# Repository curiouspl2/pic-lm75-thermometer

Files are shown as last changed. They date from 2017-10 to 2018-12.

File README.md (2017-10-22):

# pic-lm75-thermometer
pic12f629 i2c based lm75 thermometer with many ifdef options

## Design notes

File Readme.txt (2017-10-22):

.asm and .hex file for pic include gnuplot nessesities.
you can modify baudrate in the source, i've choosed 300bps
personally because it is easy to implement it for i.e. audio modem,
or optic link - faster baud rates would be problematic, and we need
such solutions because we want galvanic isolation to protect 
(expensive) PC from i.e. lightning strike induced currents.

shell script inserts date to stream from serial port. 
pic could theoretically insert own date, but it would 
1)drift 
2)make it impossible to enter sleep mode
3)increase power consumption
4)take more time to transmit over serial line

the resulting stream can be redirected to file , which can be later 
used by gnuplot to draw nie plot of temperature.

another , simpler approach would be to make pic emit also index number, 
which could be then used by gnuplot directly as X axis.
current approach is just appropriate for 'pc thermometer'.

scripts for RRD are added for convience - they are tested, and fully operational.

!!! power considerations !!!

with use of low-power lp2950 voltage regulator, and 4700uF and 2200uF capacitors 
and ad3232 (max232 equiv),
it was possible to transmit data out of 8 sensors powered from single serial port.

additional accuracy code (0.125C) for lm75A and adt75A was added, and it seems
that such amount of data is on very edge of power capacity of serial port.

addition of more capacitors is imho recommended to maintain stable supply, 
and if outdoor use is planned - perhaps small solar cell would also help.
(electronics require just 3.3V)

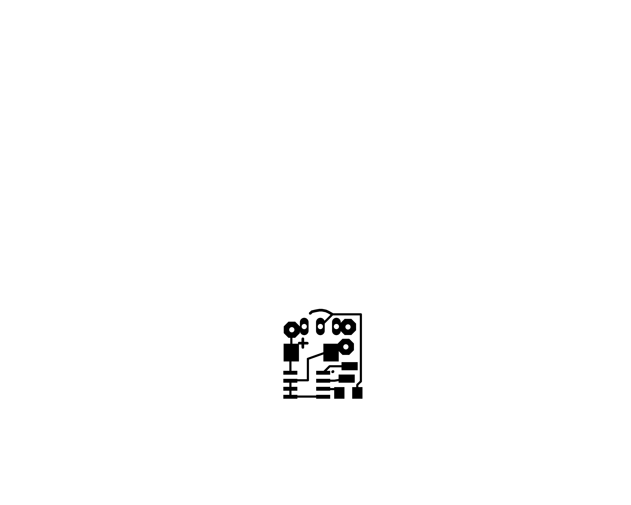
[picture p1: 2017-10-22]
lm75_daughterboard_00.png

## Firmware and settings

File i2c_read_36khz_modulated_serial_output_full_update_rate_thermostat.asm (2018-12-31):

;*******************************************************************
;
;	simple i2c thermometer
;
;	i2c thermometers in, 36khz modulated (IR compat) serial out, 
;	shift register based display with CLOCK and DATA. 
;	to interface to computer use TSOP infrared demodulator with it's output tied to RX pin (ttl)
;	TSOP works optimally at 1200bps. 
; 	if you want to switch to normal bit-banged serial - you must hack the serial routines yourself
;	(i still did not got to it, but i've left plenty of commented-out code to make it simple)
;	
;	there are few fixmes, lot of spaghetti and bit of confusing assumptions, 
; 	 but code is tested and does it's job fine.
;
;	
;*******************************************************************

;-----------features 

#define infrared_serial_output
	;//fixme - not really ifdef'd propelry yet
	; 36khz modulated serial output 
#ifdef 	infrared_serial_output
;#define splash_message
	; greeting/splash message on init/reset
;#define calibration_phase 
	;uncomment to display OSCCAL values (and calibrate serial out)
#endif 	infrared_serial_output

;#define shutdown_mode 
	; shut down lm75 after operations
;#define  sleep_mode 
	; sleep for delay
;#define  shift_register_display
	; required to have any shift register routines at all 
;#define	cooling_mode
	;//fixme 
	; global cooling or heating mode of thermostat. should be selectable for each sensor independently,
	; and from EEPROM... 
	; requires re-make of shutdown routines which mess with config register as a whole. 
	; right now setting affects ALL sensors. not defining means sensor will try to heat to set temp (active high)
#define	pseudo_analog_keyboard
	; pseudo analog keyboard. it sets KEY_[n] low, measures time taking it to get high again,
	; then sets it high and measures time taking it to get low. 
	; this is stored in two variables allowing to implement few types of keyboards. 

#ifdef	pseudo_analog_keyboard
#define	simple_two_key_keyboard
	; this is simplest two keys implementation. 
	; it requires 100nF cap and two buttons with 100ohm resistors (one to Vss , one to Vdd)
	; pros - not dependent on temperature, quality of capacitor etc. 
;#define analog_ladder_keyboard
	; using 100nF cap and set of resistors to change discharge and charge times in series with each switch. 
	;//fixme - currently not implemented
#ifdef	infrared_serial_output
#define	pseudo_analog_keyboard_infrared_serial_debug 
	;debug detected 0to1 and 1to0 transition times of keyboard
	;usefull to tune up resistor ladder keyboard resistors
#endif  infrared_serial_output

#endif 	pseudo_analog_keyboard

;------formatting
;//fixme 
; it would be nice to create new formatting theme for tv terminals displays
; idea would be to clear screen and then nicely format all sensors output so they appear in columns
; along with their additional settings like thermostats and some text descriptions 
; like :
;no  actual/setpoint/hyst
;1	22 / 24 / 22 - living room - heat pump
;2	10 / 99 / 99 - outside
;3	10 / 4 	/ 3  - garage heated with ground heat pump
;4 	-4 / -5 / -4 - fridge
;5 	 8 / 10 / 8  - fridge out to garage heat buffer
;6 	40 / 98 / 85 - solar collector critical - dump heat to garage buffer
;7	40 / 35 / 30 - solar collector low power pump
;8	25 / 25 / 30 - hybrid solar cell cooling

;#define  shift_register_display_0to7
	; use shift register display , order 0 to 7
;#define  shift_register_display_7to0
	; use shift register display, order 7 to 0 
;define	cr_only_for_gnuplot
	; uncomment to send only cr without lf - gnuplot scripts require such formatting
#define padded_output 
	; pad output to make it look pretty on serial terminals 

#define	thermostat_display
	; display thermostat settings for each sensor?
;-----
	; extra delay for i2c routines , insert nops here for longer cables
i2c_delay	macro
	nop
	nop
	nop
	nop
	nop
	nop
	nop
	nop
	endm

;--define which thermometers are enabled - only ones defined there will be initalised, woken up, read and their themostats 
updated

#define		lm75_0
#define		lm75_1
;#define	lm75_2
;#define	lm75_3
;#define	lm75_4
;#define	lm75_5
;#define	lm75_6
;#define	lm75_7

;*******************************************************************
;
;	I/O configuration
;

#ifdef	infrared_serial_output
#define S_out		GPIO,GP5	; 1200 baud , 36khz modulated serial out
#define S_out_TRIS	TRISIO,GP5	; serial port TRIS
#define S_out_WPU	WPU,GP5
#endif 	infrared_serial_output 

#define	SCL		GPIO,GP1	; GP1 - SCL
#define	SCL_tris	TRISIO,GP1	; GP1 - tris
#define SCL_WPU		WPU,GP1

#define SDA		GPIO,GP2 	; GP2 - SDA
#define SDA_tris	TRISIO,GP2 	; GP2 - tris 
#define SDA_WPU		WPU,GP2

#ifdef shift_register_display
#define DISPLAY_CLOCK	GPIO,GP4 	; GP4 - shift register CLOCK
#define DISPLAY_CLOCK_TRIS TRISIO,GP4	; GP4 - tris
#define	DISPLAY_CLOCK_WPU WPU,GP4

#define DISPLAY_DATA	GPIO,GP0	; GP5 - shift register DATA
#define DISPLAY_DATA_TRIS TRISIO,GP0	; GP5 - tris
#define	DISPLAY_DATA_WPU WPU,GP0
#endif

#ifdef	pseudo_analog_keyboard
; this keyboard implementation uses just one pin to sense few buttons.
; it requires capacitor and buttons to pull it up or down .  
#define	KEY_1		GPIO,GP4
#define KEY_1_tris	TRISIO,GP4
#define KEY_1_WPU	WPU,GP4
#endif	pseudo_analog_keyboard

;#define minus_on_last_dot 1 		; if this is defined, minus is displayed as last dot,
					; instead of 'character' - on 7 segment.
					; last dot is useless anyway, 
					; and you can re-route i's line to 'real' minus LED 
					; i.e. horizontal oriented flat blue LED, 
					; or snowflake masked LED , or whatever. 					
			;comment it out for regular displayed on first segment. obviously it will not fit on
			; 2 character displays.
#define chars_per_display	4	
 ; how many chars single display fits? used for padding, and choice to display 100's and below 1's.


;*******************************************************************
;
;	lm75 configuration
;

;#define	lm75_classic	;uncomment this to compile simplified 0.5C precission code

;*******************************************************************
;
;	CPU configuration
;

	MESSG		"Processor = 12F629"
	#define 	RAMStart	0x20
	processor	12f629
	include		<p12f629.inc>
;	__config	_INTRC_OSC_CLKOUT & _PWRTE_ON & _WDT_OFF & _CP_OFF & _BODEN_ON  & _MCLRE_OFF
	__config	_INTRC_OSC_NOCLKOUT & _PWRTE_ON & _WDT_ON & _CP_OFF & _BODEN_ON  & _MCLRE_OFF
;	__config	_HS_OSC & _PWRTE_ON & _WDT_OFF & _CP_OFF & _BODEN_ON  & _MCLRE_OFF



;----------------------------------------end of defines
;--------------------------------------------------------------end of defines
; ------------------------------------------------------------------------------end of defines


; 	code base was 16f628 frequency counter. 
; 	designed for 4mhz crystal resonator (serial IO routines)
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

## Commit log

2017-10-22 rrd and gnuplot helpers
    [12f629_i2c_rs232_out_thermometer_routed_0.2.brd, 12f629_i2c_rs232_out_thermometer_routed_0.2.sch, lm75_daughterboard_00_routed.brd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]
2017-10-22 fixed defines placement for better readability
    [i2c_read_36khz_modulated_serial_output_full_update_rate_thermostat.asm]
2017-10-28 fixes and new feats
    -tidy up and ifdef
    -fixed weak pullups mess (enough to not waste energy but it still looks ugly)
    -added pseudo analog keyboard support
    -added simplest handling of pseudo analog keyboard allowing two buttons on single pin
    -keyboard changes thermostat 0 settings, but it's possible to extend it to change settings of all thermostats
    EEPROM support is in, so changes will be permanent , ALL thermostats are also init with EEPROM table
    [i2c_read_36khz_modulated_serial_output_full_update_rate_thermostat.asm]
2018-12-31 Bugfix - no update after keypress
    thermostat was not updated after keypress -only eeprom locations were updated.
    created set_thermostats subroutine to set them all from eeprom to adt75
    which is now called both after power reset or after keypress.
    [i2c_read_36khz_modulated_serial_output_full_update_rate_thermostat.asm]
